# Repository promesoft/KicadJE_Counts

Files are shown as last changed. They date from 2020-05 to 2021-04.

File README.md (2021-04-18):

# KicadJE_Counts
Counter module as a successor to EU-3

# Purpose
## Count
10 step counter

Input +/- 10V DC
 - Clock  
 - Hold
 - Reset

Output +/- 10V DC x 10
 - Steps
 - Clock

Adjustment
 - Frequency
 - Hold

## Dist Two
Input +/- 10V DC
 - signal

Output +/- 10V DC
 - signal

Adjustment:
 - Distortion/gain section 1 (ch 1+2) feedback dist
 - Distortion/gain section 2 (ch 1+2) output stage dist + pos LED to GND

# Status - in the mail
## Initial 
| Stage  | Detail | Status |
| --- | --- | --- |
| create material  | sch | ok |
| | pcb | ok |
| | gerber | ok |
| production  | | ok |
|  | produced | ok |
|  | delivered | in the mail |
## Preliminary validation
| Test  | Detail | Status |
| --- | --- | --- |
| Initial Inspection | | OK |
| Initial Technical Test | Counts |  |
| Initial Technical Test | Dist Two | OK - all pots are reversed - LED should be moved to the free spot between input and outputs |
| Initial Product Test | Counts |  |
| Initial Product Test | Dist Two | Distorts - one channel more than the other - one input splits in two - default component values gives a lot or a little distortion |

## Secondary validation
| Test  | Detail | Status |
| --- | --- |--- |
| Product Test | Counts | |
| Product Test | Dist Two | |
| Quality | Counts | |
| Quality | Dist Two | |
| Long Term Product Test |  |  |
| Power Draw |  | 

## Errata
### Errata - Dist Two
* all pots are reversed
* default component values gives a lot or a little distortion

## Issues and Notes
### 

# Pictures
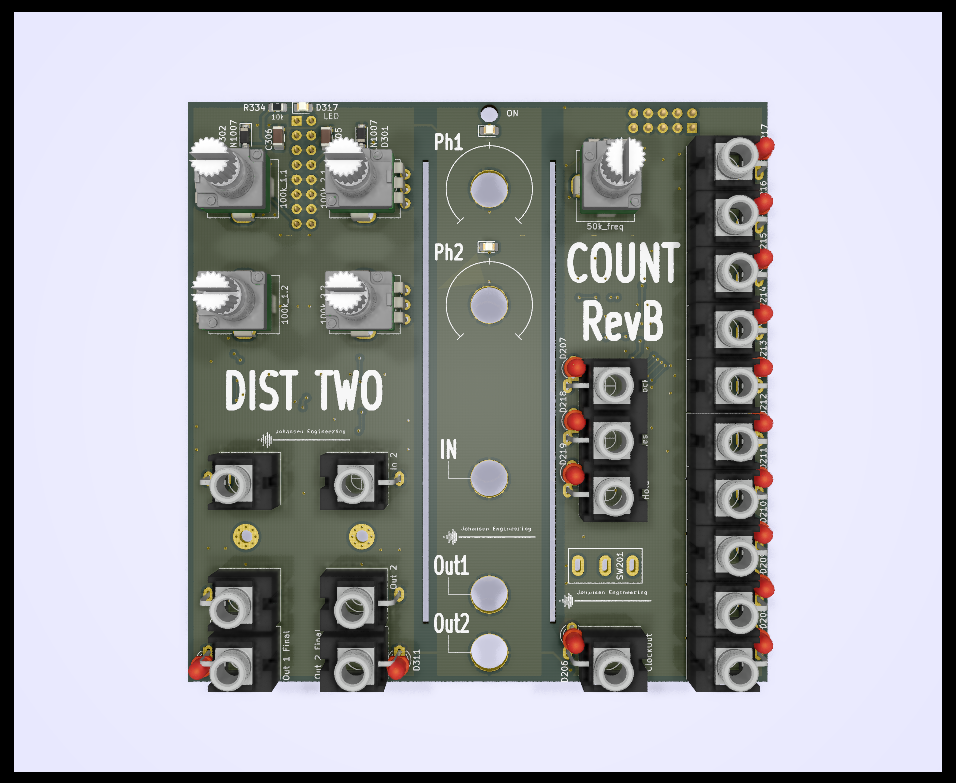
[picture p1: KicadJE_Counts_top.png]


# Schematic
## Counts
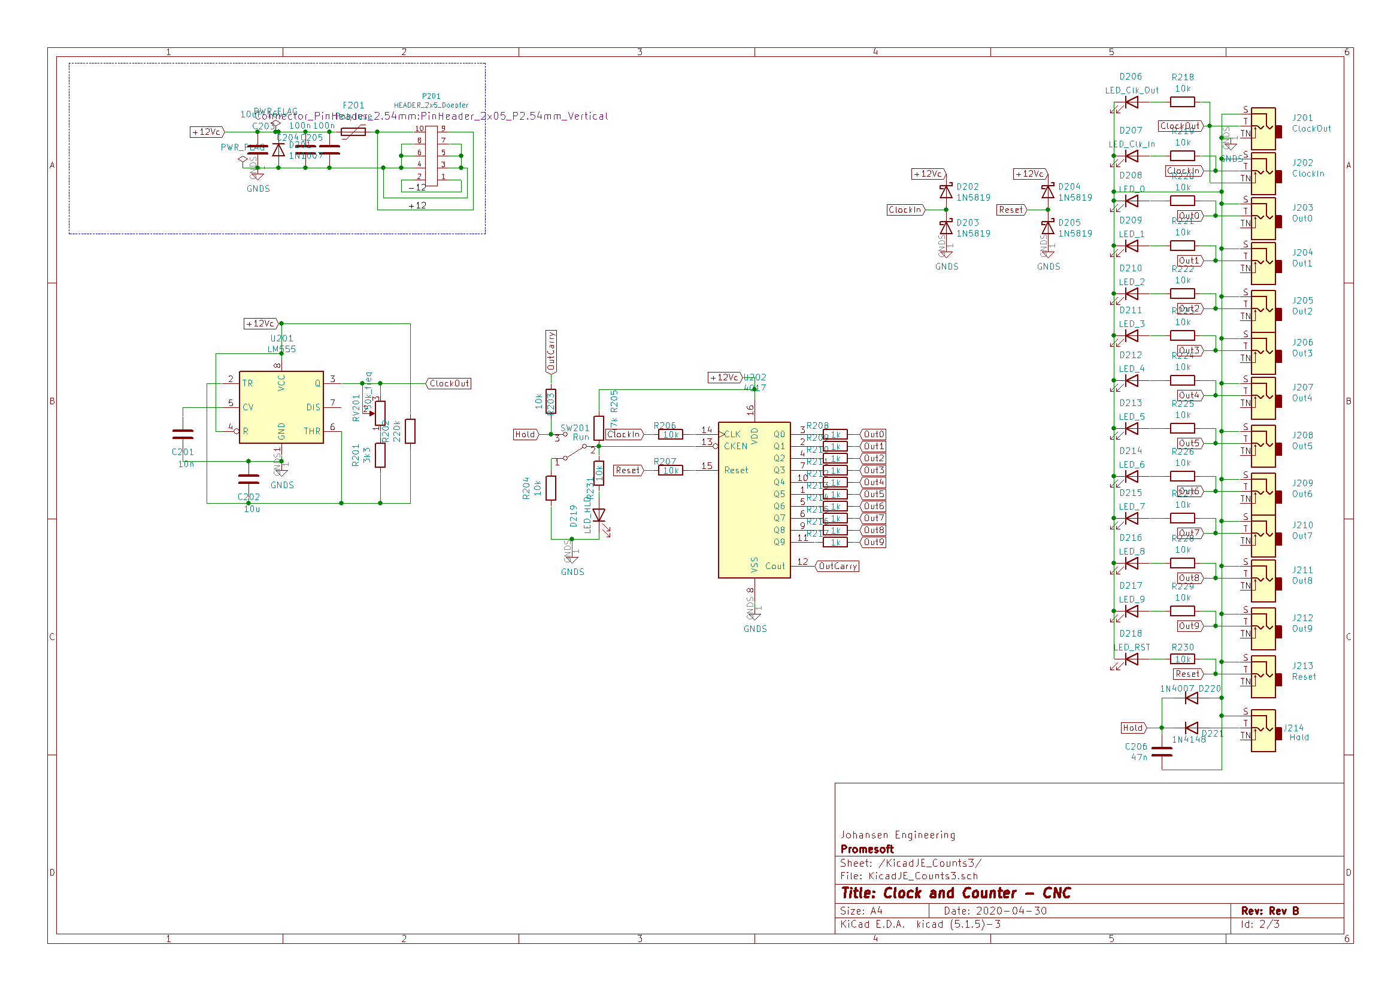
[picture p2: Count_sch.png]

## Dist Two
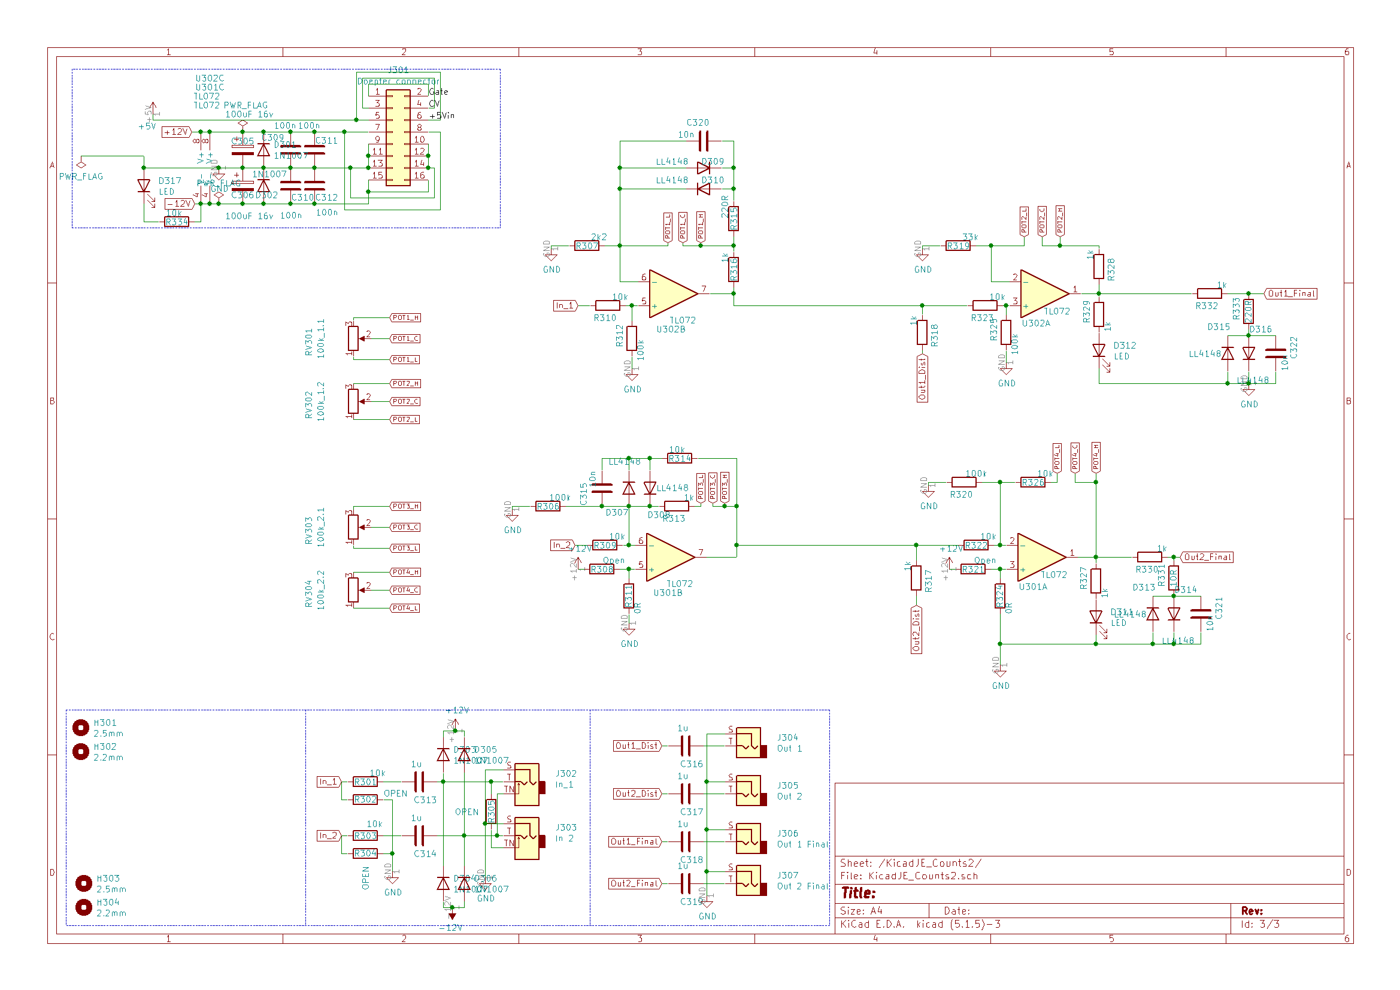
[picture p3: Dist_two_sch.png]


# Analysis
## Counts


## Prototype

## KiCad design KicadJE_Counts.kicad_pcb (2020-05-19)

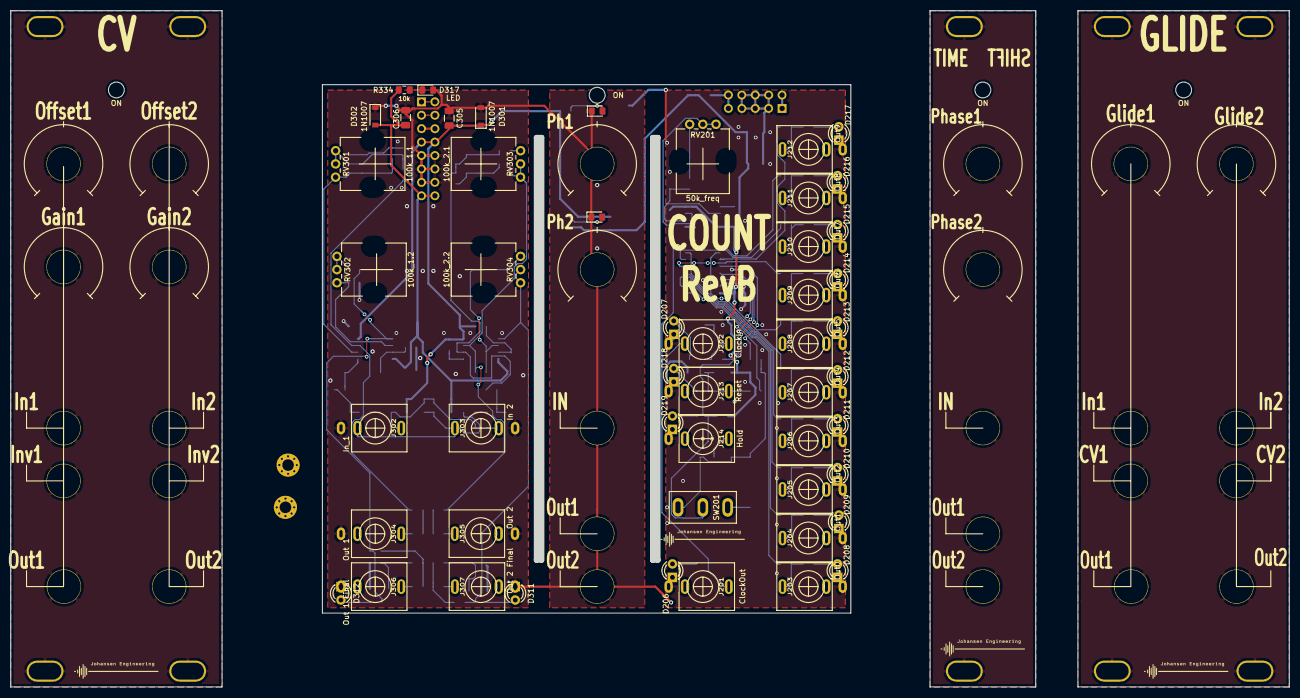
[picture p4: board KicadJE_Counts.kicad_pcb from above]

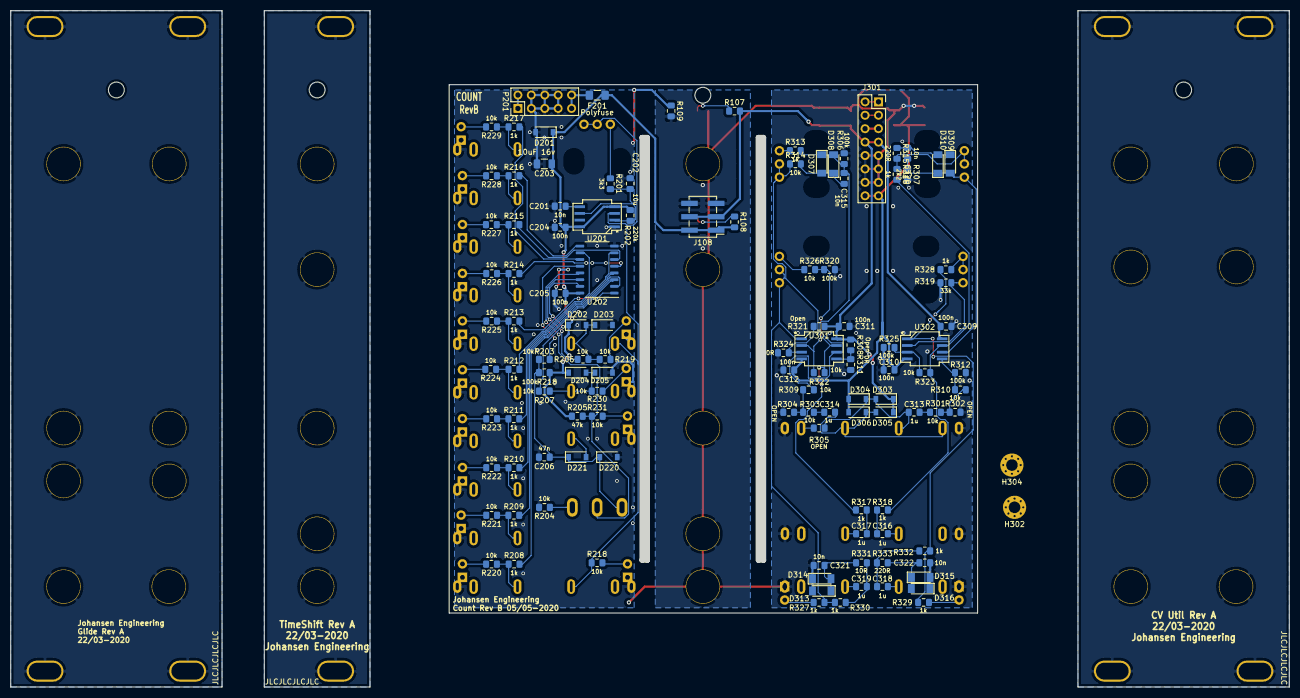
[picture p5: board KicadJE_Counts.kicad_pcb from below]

Board: 2 copper layers, 100.0 x 100.0 mm, 209 parts (122 on the bottom side), 97 nets.

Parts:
C201, C315, C320, C321, C322: 10n; C_0805_AJ
C202: 10u; C_0805_AJ
C203: 10uF 16v; C_1206_3216Metric
C204, C205, C309, C310, C311, C312: 100n; C_0805_AJ
C206: 47n; C_0805_AJ
C305, C306: 100uF 16v; C_1206_3216Metric
C313, C314, C316, C317, C318, C319: 1u; C_0805_AJ
D101, D102: D_LED; LED_0805_2012Metric_Pad1.15x1.40mm_HandSolder
D201, D301, D302, D303, D304, D305, D306: 1N1007; D_SOD-123
D202, D203, D204, D205: 1N5819; D_SOD-123
D206: LED_Clk_Out; LED_D3.0mm
D207: LED_Clk_In; LED_D3.0mm
D208: LED_0; LED_D3.0mm
D209: LED_1; LED_D3.0mm
D210: LED_2; LED_D3.0mm
D211: LED_3; LED_D3.0mm
D212: LED_4; LED_D3.0mm
D213: LED_5; LED_D3.0mm
D214: LED_6; LED_D3.0mm
D215: LED_7; LED_D3.0mm
D216: LED_8; LED_D3.0mm
D217: LED_9; LED_D3.0mm
D218: LED_RST; LED_D3.0mm
D219: LED_HLD; LED_D3.0mm
D220: 1N4007; D_SOD-123
D221: 1N4148; D_SOD-123
D307, D308, D309, D310, D313, D314, D315, D316: LL4148; D_MiniMELF
D311, D312: LED; LED_D3.0mm
D317: LED; LED_0805_2012Metric_Pad1.15x1.40mm_HandSolder
F201: Polyfuse; Fuse_1206_3216Metric_Pad1.42x1.75mm_HandSolder
H101, H101#2, H301, H301#2: ON; LED_Hole_3mm
H102, H102#2, H102#3, H103, H103#2, H103#3, H104, H104#2, H105, H105#2: MountingHole_Pad; MountingHole_Eurorack3
H302, H304: 2,2mm; MountingHole_2.2mm_M2_Pad_Via
J108: Conn_02x03_Male; PinHeader_2x03_P2.54mm_Vertical_SMD
J201: ClockOut; PJ301SM
J202: ClockIn; PJ301SM
J203: Out0; PJ301SM
J204: Out1; PJ301SM
J205: Out2; PJ301SM
J206: Out3; PJ301SM
J207: Out4; PJ301SM
J208: Out5; PJ301SM
J209: Out6; PJ301SM
J210: Out7; PJ301SM
J211: Out8; PJ301SM
J212: Out9; PJ301SM
J213: Reset; PJ301SM
J214: Hold; PJ301SM
J301: Doepfer connector; PinSocket_2x08_P2.54mm_Vertical
J302: In_1; PJ301SM
J303: In 2; PJ301SM
J304: Out 1; PJ301SM
J305: Out 2; PJ301SM
J306: Out 1 Final; PJ301SM
J307: Out 2 Final; PJ301SM
P201: HEADER_2x5_Doepfer; PinHeader_2x05_P2.54mm_Vertical
R107, R108, R109: DNP; R_0805_AJ
R201: 3k3; R_0805_AJ
R202: 220k; R_0805_AJ
R203, R204, R206, R207, R218#2, R219, R220, R221, R222, R223, R224, R225, R226, R227, R228, R229, R230, R231, R301, R303, R309, R310, R314, R322, R323, R326, R334: 10k; R_0805_AJ
R205: 47k; R_0805_AJ
R208, R209, R210, R211, R212, R213, R214, R215, R216, R217, R313, R316, R317, R318, R327, R328, R329, R330, R332: 1k; R_0805_AJ
R218, R306, R312, R320, R325: 100k; R_0805_AJ
R302, R304, R305: OPEN; R_0805_AJ
R307: 2k2; R_0805_AJ
R308, R321: Open; R_0805_AJ
R311, R324: 0R; R_0805_AJ
R315, R333: 220R; R_0805_AJ
R319: 33k; R_0805_AJ
R331: 10R; R_0805_AJ
RV201: 50k_freq; Potentiometer_China_RK09_Single_Vertical_AJ
RV301: 100k_1.1; Potentiometer_China_RK09_Single_Vertical_AJ
RV302: 100k_1.2; Potentiometer_China_RK09_Single_Vertical_AJ
RV303: 100k_2.1; Potentiometer_China_RK09_Single_Vertical_AJ
RV304: 100k_2.2; Potentiometer_China_RK09_Single_Vertical_AJ
SW201: Run; SP1MS1
TP102, TP102#2, TP303, TP303#2: SQ; Jack_6m3
TP103, TP103#2, TP301, TP301#2: In1; Jack_6m3
TP105, TP105#2: In3; Jack_6m3
TP106, TP106#2: HS; Jack_6m3
TP107, TP107#2, TP107#5: OFF1; Pot_6m3_scale1
TP107#3, TP107#4: FM; Jack_6m3
TP108, TP108#2: PWM; Jack_6m3
TP112, TP112#2, TP112#3: Fine; Pot_6m3_scale1
TP302, TP302#2: Tri; Jack_6m3
TP304, TP304#2: PWM1; Pot_6m3_scale1
TP305, TP305#2: PWM2; Pot_6m3_scale1
U201: LM555; AJ_SO-8_5.3x6.2mm_P1.27mm
U202: 4017; SOIC-16_4.55x10.3mm_P1.27mm
U301, U302: TL072; AJ_SO-8_5.3x6.2mm_P1.27mm

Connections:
+5V: J301.5, J301.6
+12V: C305.1, C309.2, C311.2, D301.1, D303.1, D305.1, J108.3, J108.4, J301.7, J301.8, R107.2, R308.2, R321.2, U301.8, U302.8
+12Vc: C203.1, C204.2, C205.2, D201.1, D202.1, D204.1, F201.2, J108.1, J108.2, R108.2, R202.1, R205.1, R218.1, U201.4, U201.8, U202.16
-12V: C306.2, C310.1, C312.1, D302.2, D304.2, D306.2, J301.15, J301.16, R334.1, U301.4, U302.4
/KicadJE_Counts2/CV: J301.3, J301.4
/KicadJE_Counts2/Gate: J301.1, J301.2
/KicadJE_Counts3/+12: F201.1, P201.9, P201.10
/KicadJE_Counts3/-12: P201.1, P201.2
ClockIn: D202.2, D203.1, J202.T, R206.2, R219.1
ClockOut: J201.T, J202.TN, R218#2.1, RV201.2, RV201.3, U201.3
GND: C305.2, C306.1, C309.1, C310.2, C311.1, C312.2, C321.2, C322.2, D101.1, D102.1, D301.2, D302.1, D311.1, D312.1, D313.2, D314.1, D315.2, D316.1, D317.2, H102.1, H102#2.1, H102#3.1, H103.1, H103#2.1, H103#3.1, H104.1, H104#2.1, H105.1, H105#2.1, J108.5, J108.6, J301.9, J301.10, J301.11, J301.12, J301.13, J301.14, J302.S, J303.S, J304.S, J305.S, J306.S, J307.S, R109.2, R302.2, R304.2, R306.2, R307.2, R311.1, R312.1, R319.2, R320.2, R324.1, R325.1, TP102.1, TP102#2.1, TP103.1, TP103#2.1, TP105.1, TP105#2.1, TP106.1, TP106#2.1, TP107.1, TP107#2.1, TP107#3.1, TP107#4.1, TP107#5.1, TP108.1, TP108#2.1, TP112.1, TP112#2.1, TP112#3.1, TP301.1, TP301#2.1, TP302.1, TP302#2.1, TP303.1, TP303#2.1, TP304.1, TP304#2.1, TP305.1, TP305#2.1
GNDS: C201.1, C202.2, C203.2, C204.1, C205.1, C206.2, D201.2, D203.2, D205.2, D206.1, D207.1, D208.1, D209.1, D210.1, D211.1, D212.1, D213.1, D214.1, D215.1, D216.1, D217.1, D218.1, D219.1, D220.2, J201.S, J202.S, J203.S, J204.S, J205.S, J206.S, J207.S, J208.S, J209.S, J210.S, J211.S, J212.S, J213.S, J214.S, P201.3, P201.4, P201.5, P201.6, P201.7, P201.8, R109.1, R204.2, U201.1, U202.8
Hold: C206.1, D220.1, D221.1, R203.2, R218.2, SW201.3
In_1: R301.2, R302.1, R310.2
In_2: R303.2, R304.1, R309.2
unnamed: C201.2, U201.5
unnamed: C202.1, R201.2, R202.2, U201.2, U201.6
unnamed: C313.1, D303.2, D304.1, J302.T, R305.1
unnamed: C313.2, R301.1
unnamed: C314.1, D305.2, D306.1, J302.TN, J303.T
unnamed: C314.2, R303.1
unnamed: C315.1, D307.2, D308.1, R306.1, R309.1, R313.2, U301.6
unnamed: C315.2, D307.1, D308.2, R314.2
unnamed: C316.1, J304.T
unnamed: C317.1, J305.T
unnamed: C318.1, J306.T
unnamed: C319.1, J307.T
unnamed: C320.2, D309.1, D310.2, R315.1
unnamed: C321.1, D313.1, D314.2, R331.1
unnamed: C322.1, D315.1, D316.2, R333.1
unnamed: D101.2, R107.1
unnamed: D102.2, R108.1
unnamed: D206.2, R218#2.2
unnamed: D207.2, R219.2
unnamed: D208.2, R220.2
unnamed: D209.2, R221.2
unnamed: D210.2, R222.2
unnamed: D211.2, R223.2
unnamed: D212.2, R224.2
unnamed: D213.2, R225.2
unnamed: D214.2, R226.2
unnamed: D215.2, R227.2
unnamed: D216.2, R228.2
unnamed: D217.2, R229.2
unnamed: D218.2, R230.2
unnamed: D219.2, R231.2
unnamed: D221.2, J214.T
unnamed: D311.2, R327.1
unnamed: D312.2, R329.1
unnamed: D317.1, R334.2
unnamed: J303.TN, R305.2
unnamed: R201.1, RV201.1
unnamed: R204.1, SW201.1
unnamed: R205.2, R231.1, SW201.2, U202.13
unnamed: R206.1, U202.14
unnamed: R207.1, U202.15
unnamed: R208.2, U202.3
unnamed: R209.2, U202.2
unnamed: R210.2, U202.4
unnamed: R211.2, U202.7
unnamed: R212.2, U202.10
unnamed: R213.2, U202.1
unnamed: R214.2, U202.5
unnamed: R215.2, U202.6
unnamed: R216.2, U202.9
unnamed: R217.2, U202.11
unnamed: R308.1, R311.2, U301.5
unnamed: R310.1, R312.2, U302.5
unnamed: R316.2, R318.1, R323.2, U302.7
unnamed: R320.1, R322.1, R326.2, U301.2
unnamed: R321.1, R324.2, U301.3
unnamed: R323.1, R325.2, U302.3
unnamed: R328.2, R329.2, R332.2, U302.1
Out0: J203.T, R208.1, R220.1
Out1: J204.T, R209.1, R221.1
Out1_Dist: C316.2, R318.2
Out1_Final: C318.2, R332.1, R333.2
Out2: J205.T, R210.1, R222.1
Out2_Dist: C317.2, R317.2
Out2_Final: C319.2, R330.1, R331.2
Out3: J206.T, R211.1, R223.1
Out4: J207.T, R212.1, R224.1
Out5: J208.T, R213.1, R225.1
Out6: J209.T, R214.1, R226.1
Out7: J210.T, R215.1, R227.1
Out8: J211.T, R216.1, R228.1
Out9: J212.T, R217.1, R229.1
OutCarry: R203.1, U202.12
POT1_C: R315.2, R316.1, RV301.2, RV301.3
POT1_L: C320.1, D309.2, D310.1, R307.1, RV301.1, U302.6
POT2_C: R328.1, RV302.2, RV302.3
POT2_L: R319.1, RV302.1, U302.2
POT3_C: R314.1, R317.1, R322.2, RV303.2, RV303.3, U301.7
POT3_L: R313.1, RV303.1
POT4_C: R327.2, R330.2, RV304.2, RV304.3, U301.1
POT4_L: R326.1, RV304.1
Reset: D204.2, D205.1, J213.T, R207.2, R230.1

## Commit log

2020-04-30 counter fine
    [KicadJE_Counts.sch, KicadJE_Counts2.sch, KicadJE_Counts3.sch]
2020-05-02 distortion added as count2
    [KicadJE_Counts.sch, KicadJE_Counts2.sch, KicadJE_Counts2_1.sch]
2020-05-04 Clk I/O
    [template.kicad_pcb]
2020-05-04 sch updates
    [KicadJE_Counts.sch, KicadJE_Counts2.sch, KicadJE_Counts3.sch]
2020-05-04 footprint updates
    [KicadJE_Counts.sch, KicadJE_Counts2.sch, KicadJE_Counts3.sch]
2020-05-04 major components placed for counter
    [KicadJE_Counts.kicad_pcb, KicadJE_Counts3.sch]
2020-05-05 Count routed w component labels
    [KicadJE_Counts.kicad_pcb]
2020-05-05 Update KicadJE_Counts.kicad_pcb
    Count labels
    [KicadJE_Counts.kicad_pcb]
2020-05-18 Update KicadJE_Counts2.sch
    Dummy diode light
    [KicadJE_Counts2.sch]
2020-05-18 Update KicadJE_Counts.sch
    GND conn
    [KicadJE_Counts.sch]
2020-05-18 Update KicadJE_Counts.kicad_pcb
    LED and GND on center panel
    [KicadJE_Counts.kicad_pcb]
2020-05-18 Update KicadJE_Counts.sch
    conn for led
    [KicadJE_Counts.sch]
2020-05-18 change header pin out
    [KicadJE_Counts.sch]
2020-05-18 cleanup old conn
    [KicadJE_Counts.kicad_pcb, KicadJE_Counts.sch]
2020-05-18 Update KicadJE_Counts.kicad_pcb
    input circuit
    [KicadJE_Counts.kicad_pcb]
2020-05-18 Update KicadJE_Counts2.sch
    conn pots
    [KicadJE_Counts2.sch]
2020-05-18 Changed label types for POT's
    [KicadJE_Counts.kicad_pcb, KicadJE_Counts2.sch]
2020-05-19 Update KicadJE_Counts.kicad_pcb
    components placed
    [KicadJE_Counts.kicad_pcb]
2020-05-19 Update KicadJE_Counts.kicad_pcb
    wired
    [KicadJE_Counts.kicad_pcb]
2020-05-19 Update KicadJE_Counts.kicad_pcb
    DRC
    [KicadJE_Counts.kicad_pcb]
2020-05-19 PCB Labels
    [KicadJE_Counts_PCB.kicad_pcb]
